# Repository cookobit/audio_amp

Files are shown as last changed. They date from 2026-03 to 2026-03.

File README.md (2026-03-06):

# TPA3251 Audio Amplifier (Current main rev v0.1a)

Repository has an amplifier board under development for self entertainment and for self studies.

### Initial targets:
With this project I want to achieve the following:

1. The output THD + N should remain low: **<0.1%**. 

    * The solution of capturing this measurement requires personal research. The metric is specified.
2. Make the amplifier sound good!
3. Learn the design process and learn the tools over the project advancement.
4. Learn how to design filters.

---
### Hardware requirements:

* Amplifier circuit (Done)
* Pre-amplifier circuit
* UI (indicator LEDs, volume control)
* 2x speaker output ports
* 1x USB-C Input interface --> DAC module integration (might develop my own one, if interested)
* 1x 3.5mm Input
* 1x Power Flip Switch (I always wanted such)
---
#### Defined Characteristics:
V = 24V - 36V (most cases) 

#### Power tree: 
36V TPA3251_PVDD
  --> 15V 
    --> 12V TPA3251_VDD
      --> 3.3V LEDs, (MCU?)
      
(might require 5V)

---
### Known issues:
1. Buck converter wrong connection
2. Indicator LED driver MOSFETs have a wrong arrangement
3. Update LM5010-12 footprint (at the moment its for the *-8.0)
---
# Future development as of 5th of March, 2026

Consider using 4-layer board --> miniturize
Start designing pre-amplifier and volume control

1. LTSpice pre-amp circuit with volume control. (Bass..?)
2. After pre amp circuit is done and valid, add the UI terminal in circuit. (Interfaces, LED indicators)
3. After UI, DAC module, Bluetooth?
4. Controlling MCU + flash option.
5. Update the board design. Merge updates.

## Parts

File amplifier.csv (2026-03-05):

Reference | Qty | Value | DNP | Exclude from BOM | Exclude from Board | Footprint | Datasheet
C1 | 1 | 47u |  |  |  | Capacitor_SMD:CP_Elec_6.3x5.9 | ~
C2 | 1 | 0.1u |  |  |  | Capacitor_SMD:C_0805_2012Metric_Pad1.18x1.45mm_HandSolder | ~
C3 | 1 | 10u |  |  |  | Capacitor_SMD:CP_Elec_4x5.4 | ~
C4 | 1 | 100u |  |  |  | Capacitor_SMD:CP_Elec_5x5.9 | ~
C5 | 1 | 4.7u |  |  |  | Capacitor_SMD:C_1206_3216Metric_Pad1.33x1.80mm_HandSolder | ~
C6 | 1 | 470n |  |  |  | Capacitor_SMD:C_0603_1608Metric_Pad1.08x0.95mm_HandSolder | ~
C7 | 1 | 5600p |  |  |  | Capacitor_SMD:C_0603_1608Metric_Pad1.08x0.95mm_HandSolder | ~
C8 | 1 | 47n |  |  |  | Capacitor_SMD:C_0402_1005Metric_Pad0.74x0.62mm_HandSolder | ~
C9 | 1 | 2.2u |  |  |  | Capacitor_SMD:C_0805_2012Metric_Pad1.18x1.45mm_HandSolder | ~
C10,C12,C14,C15,C31,C32,C41 | 7 | 100n |  |  |  | Capacitor_SMD:C_0805_2012Metric_Pad1.18x1.45mm_HandSolder | ~
C11 | 1 | 4.7n |  |  |  | Capacitor_SMD:C_0603_1608Metric_Pad1.08x0.95mm_HandSolder | ~
C13,C16,C26,C27,C33 | 5 | 1u |  |  |  | Capacitor_SMD:C_0805_2012Metric_Pad1.18x1.45mm_HandSolder | ~
C17,C34 | 2 | 1000u |  |  |  | Capacitor_THT:CP_Radial_D16.0mm_P7.50mm | ~
C18,C21,C35,C38 | 4 | 10u |  |  |  | Capacitor_SMD:C_Elec_4x5.4 | ~
C19,C28,C36,C44 | 4 | 33n |  |  |  | Capacitor_SMD:C_0603_1608Metric_Pad1.08x0.95mm_HandSolder | ~
C20,C29,C30,C37,C45 | 5 | 10n |  |  |  | Capacitor_SMD:C_0603_1608Metric_Pad1.08x0.95mm_HandSolder | ~
C22,C24,C39,C42 | 4 | 1u |  |  |  | Capacitor_THT:C_Rect_L18.0mm_W8.0mm_P15.00mm_FKS3_FKP3 | ~
C23,C25,C40,C43 | 4 | 1n |  |  |  | Capacitor_SMD:C_0603_1608Metric_Pad1.08x0.95mm_HandSolder | ~
D1 | 1 | 100V/1A |  |  |  | Diode_SMD:D_SMA_Handsoldering | ~
D2 | 1 | 100V/3A |  |  |  | Diode_SMD:D_SMA_Handsoldering | ~
D3 | 1 | Green - Power |  |  |  | LED_SMD:LED_0805_2012Metric_Pad1.15x1.40mm_HandSolder | ~
D4 | 1 | Red - Fault |  |  |  | LED_SMD:LED_0805_2012Metric_Pad1.15x1.40mm_HandSolder | ~
D5 | 1 | Orange - OTW |  |  |  | LED_SMD:LED_0805_2012Metric_Pad1.15x1.40mm_HandSolder | ~
HS1 | 1 | Heatsink_Pad_2Pin |  |  |  | HSB38-707025P:HSINK_HSB38-707025P | ~
IC1 | 1 | LM2940IMPX-8.0_NOPB |  |  |  | Package_TO_SOT_SMD:SOT-223 | http://www.ti.com/lit/gpn/lm2940-n
IC2 | 1 | LM5010MH_NOPB |  |  |  | Package_SO:Texas_HTSSOP-14-1EP_4.4x5mm_P0.65mm_EP3.4x5mm_Mask3.155x3.255mm | http://www.ti.com/lit/gpn/lm5010
J1,J2,J3,J4,J5 | 5 | Screw_Terminal_01x02 |  |  |  | TerminalBlock_Phoenix:TerminalBlock_Phoenix_MKDS-1,5-2_1x02_P5.00mm_Horizontal | ~
L1 | 1 | 100uH 1.5A |  |  |  | Inductor_SMD:L_10.4x10.4_H4.8 | ~
L2,L3,L4,L5 | 4 | 10u |  |  |  | Inductor_SMD:L_Wuerth_HCF-2013 | ~
Q1,Q2 | 2 | NMOS |  |  |  | Package_TO_SOT_SMD:SOT-23-3 | https://ngspice.sourceforge.io/docs/ngspice-html-manual/manual.xhtml#cha_MOSFETs
R1 | 1 | 4.99k |  |  |  | Resistor_SMD:R_0805_2012Metric_Pad1.20x1.40mm_HandSolder | ~
R2 | 1 | 182k |  |  |  | Resistor_SMD:R_0805_2012Metric_Pad1.20x1.40mm_HandSolder | ~
R3,R14,R15 | 3 | 1k |  |  |  | Resistor_SMD:R_0805_2012Metric_Pad1.20x1.40mm_HandSolder | ~
R4 | 1 | 499 |  |  |  | Resistor_SMD:R_0805_2012Metric_Pad1.20x1.40mm_HandSolder | ~
R5,R6,R9,R10,R12,R13 | 6 | 3R3 |  |  |  | Resistor_SMD:R_0805_2012Metric_Pad1.20x1.40mm_HandSolder | ~
R7 | 1 | 22k |  |  |  | Resistor_SMD:R_0805_2012Metric_Pad1.20x1.40mm_HandSolder | ~
R8 | 1 | 10k |  |  |  | Resistor_SMD:R_0805_2012Metric_Pad1.20x1.40mm_HandSolder | ~
R11,R16,R17 | 3 | 47k |  |  |  | Resistor_SMD:R_0805_2012Metric_Pad1.20x1.40mm_HandSolder | ~
R18,R19 | 2 | 100 |  |  |  | Resistor_SMD:R_0805_2012Metric_Pad1.20x1.40mm_HandSolder | ~
SW1 | 1 | SW_Push |  |  |  | Button_Switch_SMD:SW_SPST_Omron_B3FS-100xP | ~
TP1,TP2,TP3,TP4,TP5,TP6,TP7,TP8,TP9,TP10,TP11,TP12,TP13 | 13 | TestPoint |  |  |  | TestPoint:TestPoint_Loop_D2.50mm_Drill1.0mm_LowProfile | ~
U1 | 1 | TLV1117-33 |  |  |  | Package_TO_SOT_SMD:SOT-223-3_TabPin2 | http://www.ti.com/lit/ds/symlink/tlv1117.pdf
U2 | 1 | TPA3251 |  |  |  | Package_SO:HTSSOP-44_6.1x14mm_P0.635mm_TopEP4.14x7.01mm | http://www.ti.com/lit/ds/symlink/tpa3251.pdf

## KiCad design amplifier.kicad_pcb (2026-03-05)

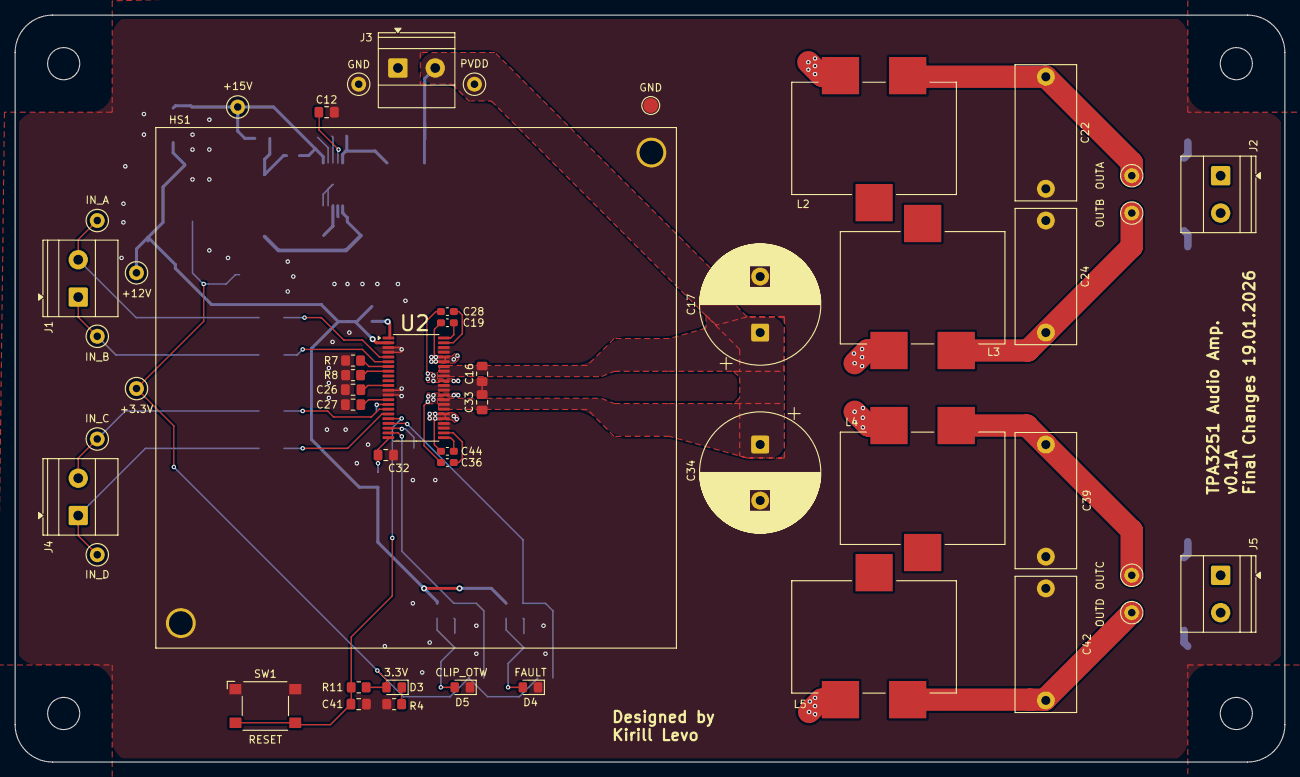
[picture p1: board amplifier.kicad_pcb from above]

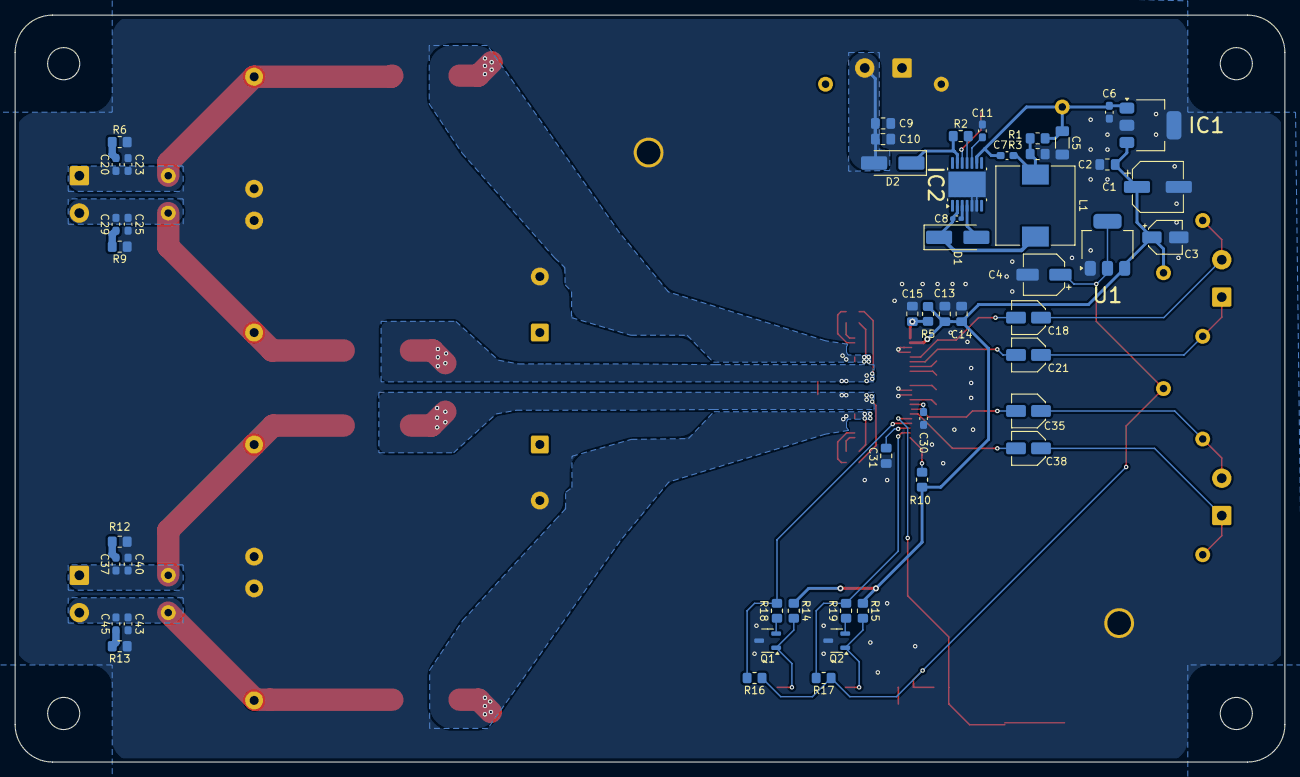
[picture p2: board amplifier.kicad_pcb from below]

Board: 2 copper layers, 170.0 x 100.0 mm, 101 parts (51 on the bottom side), 53 nets.

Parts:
+3.3V, +12V, +15V: TestPoint; TestPoint_Loop_D2.50mm_Drill1.0mm_LowProfile
C1: 47u; CP_Elec_6.3x5.9
C2: 0.1u; C_0805_2012Metric_Pad1.18x1.45mm_HandSolder
C3: 10u; CP_Elec_4x5.4
C4: 100u; CP_Elec_5x5.9
C5: 4.7u; C_1206_3216Metric_Pad1.33x1.80mm_HandSolder
C6: 470n; C_0603_1608Metric_Pad1.08x0.95mm_HandSolder
C7: 5600p; C_0603_1608Metric_Pad1.08x0.95mm_HandSolder
C8: 47n; C_0402_1005Metric_Pad0.74x0.62mm_HandSolder
C9: 2.2u; C_0805_2012Metric_Pad1.18x1.45mm_HandSolder
C10, C12, C14, C15, C31, C32, C41: 100n; C_0805_2012Metric_Pad1.18x1.45mm_HandSolder
C11: 4.7n; C_0603_1608Metric_Pad1.08x0.95mm_HandSolder
C13, C16, C26, C27, C33: 1u; C_0805_2012Metric_Pad1.18x1.45mm_HandSolder
C17, C34: 1000u; CP_Radial_D16.0mm_P7.50mm
C18, C21, C35, C38: 10u; C_Elec_4x5.4
C19, C28, C36, C44: 33n; C_0603_1608Metric_Pad1.08x0.95mm_HandSolder
C20, C29, C30, C37, C45: 10n; C_0603_1608Metric_Pad1.08x0.95mm_HandSolder
C22, C24, C39, C42: 1u; C_Rect_L18.0mm_W8.0mm_P15.00mm_FKS3_FKP3
C23, C25, C40, C43: 1n; C_0603_1608Metric_Pad1.08x0.95mm_HandSolder
D1: 100V/1A; D_SMA_Handsoldering
D2: 100V/3A; D_SMA_Handsoldering
D3: Green - Power; LED_0805_2012Metric_Pad1.15x1.40mm_HandSolder
D4: Red - Fault; LED_0805_2012Metric_Pad1.15x1.40mm_HandSolder
D5: Orange - OTW; LED_0805_2012Metric_Pad1.15x1.40mm_HandSolder
GND: TestPoint; TestPoint_Loop_D2.50mm_Drill1.0mm_LowProfile
GND#2: TestPoint_Pad_D2.0mm
HS1: Heatsink_Pad_2Pin; HSINK_HSB38-707025P
IC1: LM2940IMPX-8.0_NOPB; SOT-223
IC2: LM5010MH_NOPB; Texas_HTSSOP-14-1EP_4.4x5mm_P0.65mm_EP3.4x5mm_Mask3.155x3.2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
IN_A: TestPoint; TestPoint_Loop_D2.50mm_Drill1.0mm_LowProfile
IN_B: TestPoint; TestPoint_Loop_D2.50mm_Drill1.0mm_LowProfile
IN_C: TestPoint; TestPoint_Loop_D2.50mm_Drill1.0mm_LowProfile
IN_D: TestPoint; TestPoint_Loop_D2.50mm_Drill1.0mm_LowProfile
J1, J2, J3, J4, J5: Screw_Terminal_01x02; TerminalBlock_Phoenix_MKDS-1,5-2_1x02_P5.00mm_Horizontal
L1: 100uH 1.5A; L_10.4x10.4_H4.8
L2, L3, L4, L5: 10u; L_Wuerth_HCF-2013
OUTA: TestPoint; TestPoint_Loop_D2.50mm_Drill1.0mm_LowProfile
OUTB: TestPoint; TestPoint_Loop_D2.50mm_Drill1.0mm_LowProfile
OUTC: TestPoint; TestPoint_Loop_D2.50mm_Drill1.0mm_LowProfile
OUTD: TestPoint; TestPoint_Loop_D2.50mm_Drill1.0mm_LowProfile
PVDD: TestPoint; TestPoint_Loop_D2.50mm_Drill1.0mm_LowProfile
Q1, Q2: NMOS; SOT-23-3
R1: 4.99k; R_0805_2012Metric_Pad1.20x1.40mm_HandSolder
R2: 182k; R_0805_2012Metric_Pad1.20x1.40mm_HandSolder
R3, R14, R15: 1k; R_0805_2012Metric_Pad1.20x1.40mm_HandSolder
R4: 499; R_0805_2012Metric_Pad1.20x1.40mm_HandSolder
R5, R6, R9, R10, R12, R13: 3R3; R_0805_2012Metric_Pad1.20x1.40mm_HandSolder
R7: 22k; R_0805_2012Metric_Pad1.20x1.40mm_HandSolder
R8: 10k; R_0805_2012Metric_Pad1.20x1.40mm_HandSolder
R11, R16, R17: 47k; R_0805_2012Metric_Pad1.20x1.40mm_HandSolder
R18, R19: 100; R_0805_2012Metric_Pad1.20x1.40mm_HandSolder
SW1: SW_Push; SW_SPST_Omron_B3FS-100xP
U1: TLV1117-33; SOT-223-3_TabPin2
U2: TPA3251; HTSSOP-44_6.1x14mm_P0.635mm_TopEP4.14x7.01mm

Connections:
+3.3V: +3.3V.1, C4.1, D3.2 (A), R11.1, R16.1, R17.1, U1.2 (VO)
+12V: +12V.1, C1.1, C2.1, C3.1, C13.2, C14.2, IC1.3 (OUT), R5.1, R10.1, R14.1, R15.1, U1.3 (VI), U2.2 (VDD)
+15V: +15V.1, C5.1, C6.1, C7.1, IC1.1 (IN), IC2.9 (FB), R1.1
/CLIP_OTW: R17.2, R19.1, U2.21 (~CLIP_OTW)
/FAULT: R16.2, R18.1, U2.19 (~FAULT)
/OUTA: C20.2, C22.1, C23.1, J2.1, L2.2, OUTA.1
/OUTB: C24.2, C25.2, C29.2, J2.2, L3.2, OUTB.1
/OUTC: C37.2, C39.1, C40.1, J5.1, L4.2, OUTC.1
/OUTD: C42.2, C43.2, C45.2, J5.2, L5.2, OUTD.1
/Orange: D5.2 (A), Q2.1 (D), R15.2
/PWMA: C19.2, L2.1, U2.39 (OUT_A), U2.40 (OUT_A)
/PWMB: C28.1, L3.1, U2.35 (OUT_B)
/PWMC: C36.2, L4.1, U2.32 (OUT_C)
/PWMD: C44.1, L5.1, U2.27 (OUT_D), U2.28 (OUT_D)
/RESET: C41.1, R11.2, SW1.2, U2.18 (~RESET)
/Red: D4.2 (A), Q1.1 (D), R14.2
/input_a: C18.1, IN_A.1, J1.2
/input_b: C21.1, IN_B.1, J1.1
/input_c: C35.1, IN_C.1, J4.2
/input_d: C38.1, IN_D.1, J4.1
GND: C1.2, C2.2, C3.2, C4.2, C5.2, C6.2, C9.2, C10.2, C11.2, C12.2, C13.1, C14.1, C15.1, C16.1, C17.2, C22.2, C23.2, C24.1, C25.1, C26.1, C27.1, C30.1, C31.1, C32.1, C33.1, C34.2, C39.2, C40.2, C41.2, C42.1, C43.1, D4.1 (K), D5.1 (K), GND.1, GND#2.1, HS1.1, HS1.2, IC1.2 (GND), IC1.4 (PAD), IC2.5 (SGND), IC2.6 (RTN), IC2.15 (EP), J3.1, Q1.3 (S), Q2.3 (S), R3.2, R4.2, R6.2, R7.1, R8.1, R9.1, R12.2, R13.1, SW1.1, U1.1 (GND), U2.3 (M1), U2.4 (M2), U2.12 (GND), U2.13 (GND), U2.25 (GND), U2.26 (GND), U2.33 (GND), U2.34 (GND), U2.41 (GND), U2.42 (GND)
unnamed: C7.2, L1.2, R1.2, R3.1
unnamed: C20.1, R6.1
unnamed: C29.1, R9.2
unnamed: C37.1, R12.1
unnamed: C45.1, R13.2
unnamed: D1.2 (A), IC2.4 (ISEN)
unnamed: C8.1, D1.1 (K), IC2.2 (SW), L1.1
unnamed: D2.1 (K), IC2.13 (VIN), R2.1
unnamed: D3.1 (K), R4.1
unnamed: C8.2, IC2.3 (BST)
unnamed: IC2.11 (RON/SD), R2.2
unnamed: C11.1, IC2.10 (SS)
unnamed: C12.1, IC2.12 (VCC)
unnamed: Q1.2 (G), R18.2
unnamed: Q2.2 (G), R19.2
unnamed: C27.2, U2.14 (AVDD)
unnamed: C19.1, U2.44 (BST_A)
unnamed: C28.2, U2.43 (BST_B)
unnamed: C30.2, U2.15 (C_START)
unnamed: C26.2, U2.11 (DVDD)
unnamed: R8.2, U2.8 (FREQ_ADJ)
unnamed: C15.2, R5.2, U2.1 (GVDD_AB)
unnamed: C18.2, U2.5 (INPUT_A)
unnamed: C21.2, U2.6 (INPUT_B)
unnamed: R7.2, U2.7 (OC_ADJ)
unnamed: C31.2, U2.20 (VBG)
unnamed: C36.1, U2.24 (BST_C)
unnamed: C44.2, U2.23 (BST_D)
unnamed: C32.2, R10.2, U2.22 (GVDD_CD)
unnamed: C35.2, U2.16 (INPUT_C)
unnamed: C38.2, U2.17 (INPUT_D)
PVDD: C9.1, C10.1, C16.2, C17.1, C33.2, C34.1, D2.2 (A), J3.2, PVDD.1, U2.29 (PVDD_CD), U2.30 (PVDD_CD), U2.31 (PVDD_CD), U2.36 (PVDD_AB), U2.37 (PVDD_AB), U2.38 (PVDD_AB)

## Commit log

2026-03-05 Initial commit after starting the usage of version control
    [amplifier-B_Cu.gbr, amplifier-B_Mask.gbr, amplifier-B_Paste.gbr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]
2026-03-05 Restructure and renaming
    [amplifier-B_Cu.gbr, amplifier-B_Mask.gbr, amplifier-B_Paste.gbr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]
